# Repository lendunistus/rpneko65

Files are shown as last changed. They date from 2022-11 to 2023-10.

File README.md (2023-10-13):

# RPNeko65

**This revision has several flaws. I do not recommend actually getting this manufactured. A second revision is currently work-in-progress in the rev2 branch.**

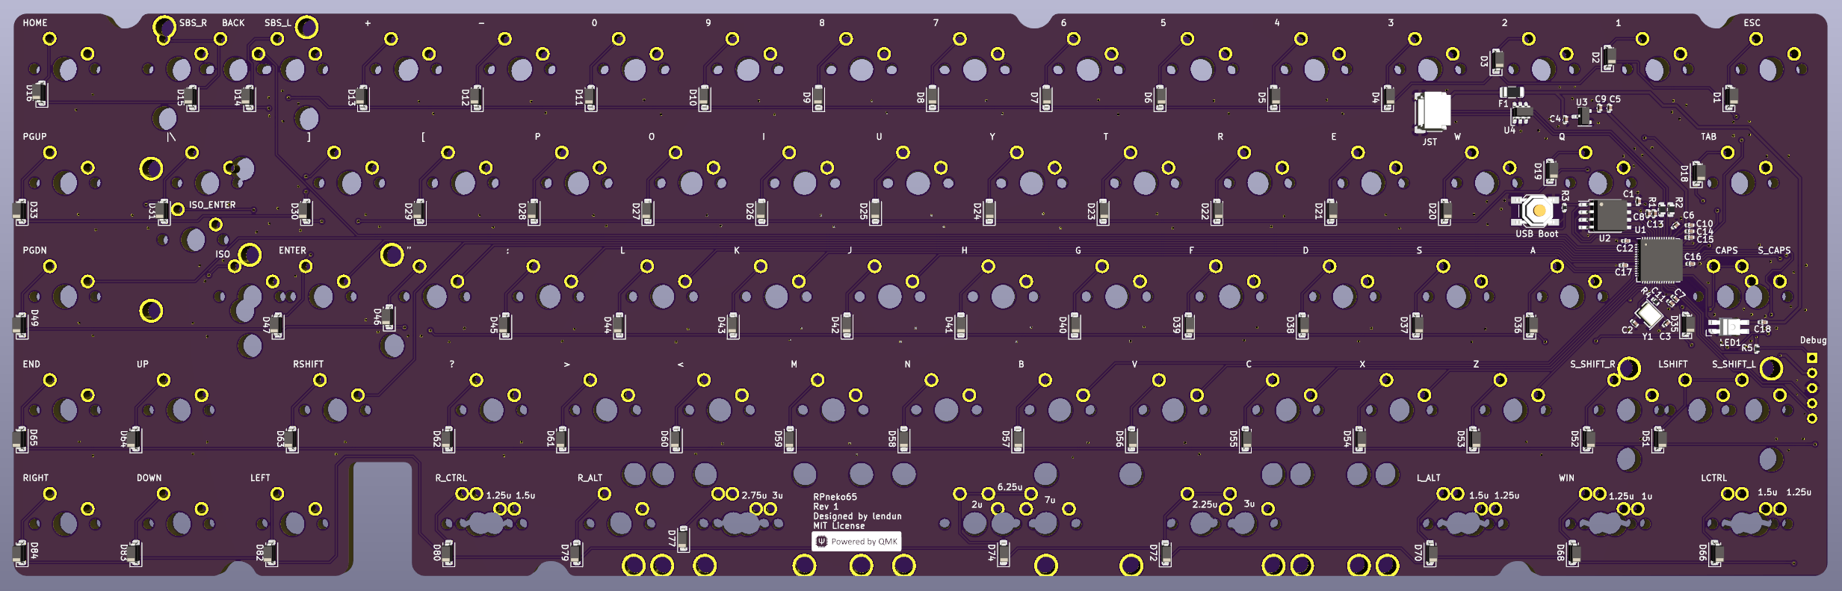
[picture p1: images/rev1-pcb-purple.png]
PCB Image


An open source multi-layout PCB for the [Bakeneko65](https://github.com/kkatano/bakeneko-65)

## Features
- QMK/VIA
- RGB LED under Caps Lock (currently non-functional without modification)
- Large amount of layout support
- C3 Unified Daughterboard
- Support for clip-in stabilizers

## Layout support
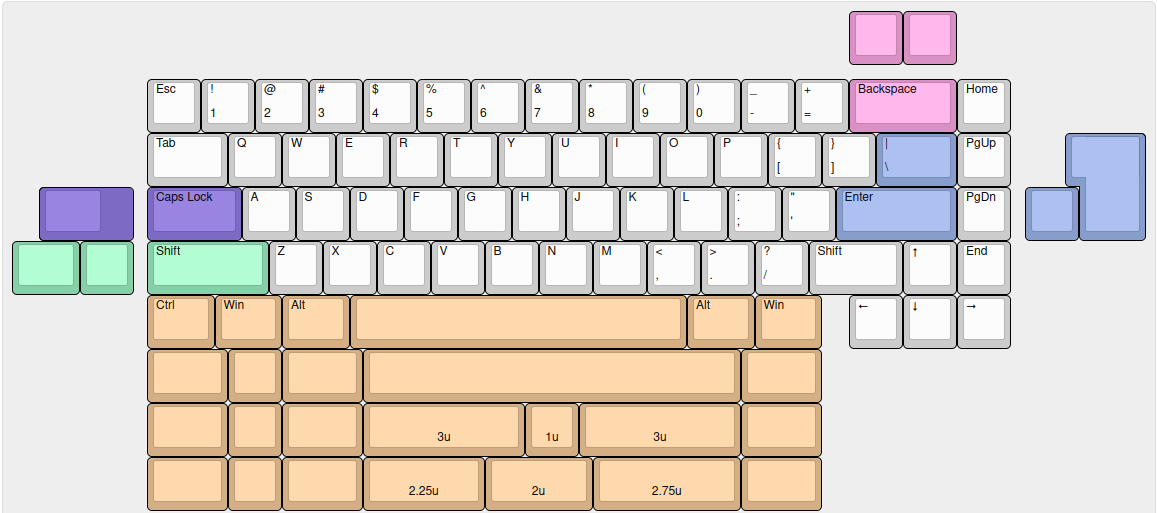
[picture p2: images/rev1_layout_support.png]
Layout Support


## Release history
- Rev 1: Initial prototype. Caps Lock LED is non-functional due to incorrect capacitor wiring, can be fixed by removing the capacitor and bridging the two pads. ANSI enter and spacebar stabiliser holes are also misaligned

## Credits
- kkatano for creating the original Bakeneko65
- Zykrah for their [firmware script](https://github.com/zykrah/firmware-scripts)
- MarvFPV and ebastler for [marbastlib](https://github.com/ebastler/marbastlib)
- Sleepdealer for their [RP2040 design guide](https://github.com/Sleepdealr/RP2040-designguide)
- People in the Keyboard Atelier server for the help and assistance

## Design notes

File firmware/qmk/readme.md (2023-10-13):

# rpneko65

rpneko65\
*PCB rear side*

A multi-layout PCB designed to fit the Bakeneko65 case by kkatano.

* Keyboard Maintainer: [lendunistus](https://github.com/lendunistus)
* Hardware Supported: RPNeko65 PCB; [Bakeneko65 V3 Case](https://github.com/kkatano/bakeneko-65)
* Hardware Availability: [Open source on GitHub](https://github.com/lendunistus/rpneko65)

Make example for this keyboard (after setting up your build environment):

    make lendunistus/rpneko65/rev1:default

Flashing example for this keyboard:

    make lendunistus/rpneko65/rev1:default:flash

See the [build environment setup](https://docs.qmk.fm/#/getting_started_build_tools) and the [make instructions](https://docs.qmk.fm/#/getting_started_make_guide) for more information. Brand new to QMK? Start with our [Complete Newbs Guide](https://docs.qmk.fm/#/newbs).

## Bootloader

Plug in the keyboard while holding down either the ESC key or the button on the back of the PCB labelled "USB Boot".

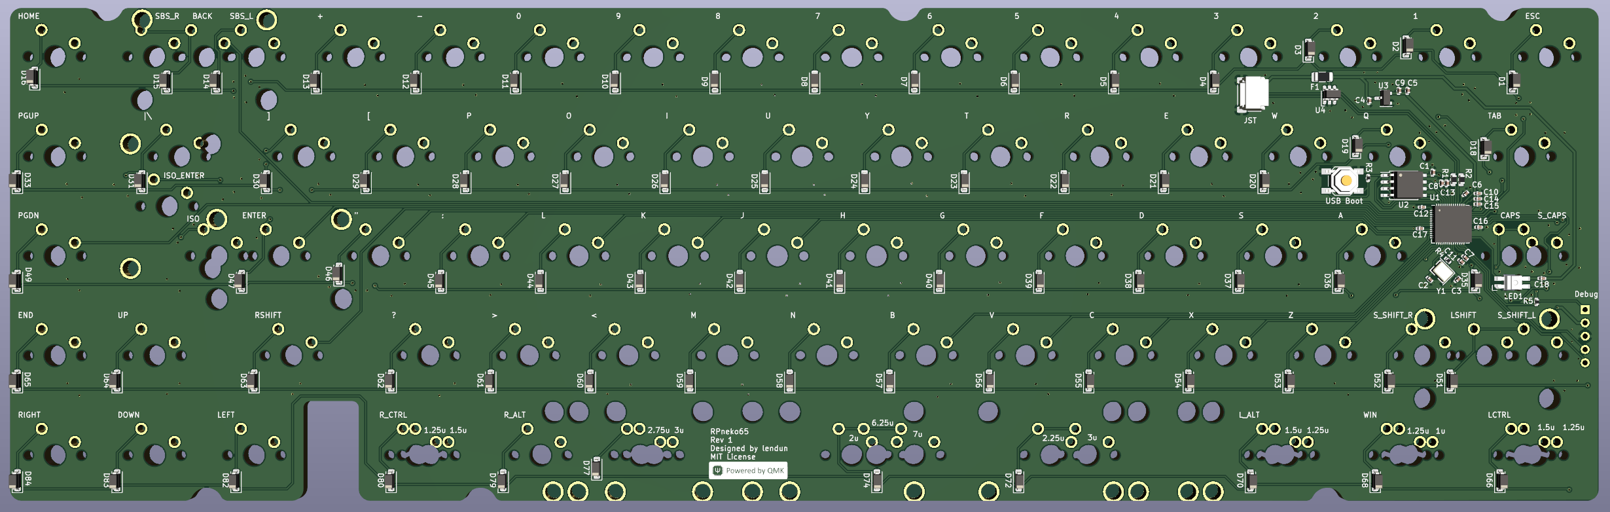
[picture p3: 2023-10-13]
images/rev1-pcb.png

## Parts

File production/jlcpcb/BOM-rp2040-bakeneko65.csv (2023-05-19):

Comment | Designator | Footprint | LCSC
1k | R3,R4,R5 | R_0402_1005Metric | C11702
500mA | F1 | Fuse_1206_3216Metric | C151162
22pF | C2,C3 | C_0402_1005Metric | C1555
SM04B-SRSS-TB | J1 | JST_SH_SM04B-SRSS-TB_1x04-1MP_P1.00mm_Horizontal | C160404
RP2040 | U1 | QFN-56-1EP_7x7mm_P0.4mm_EP3.2x3.2mm | C2040
4.7uF | C9 | C_0402_1005Metric | C23733
27 | R1,R2 | R_0603_1608Metric | C25190
100nF | C1,C11,C12,C13,C14,C15,C16,C17,C18,C7,C8 | C_0402_1005Metric | C307331
SW_Push | SW85 | SW_SPST_SKQG_WithStem | C318884
SK6812 Mini-E | LED1 | LED_MX_6028R | C524051
1uF | C10,C4,C5,C6 | C_0402_1005Metric | C52923
XC6206PxxxMR | U3 | SOT-23 | C5446
1N4148 | D1,D10,D11,D12,D13,D14,D15,D16,D18,D19,D2,D20,D21,D22,D23,D24,D25,D26,D27,D28,D29,D3,D30,D31,D33,D35,D36,D37,D38,D39,D4,D40,D41,D42,D43,D44,D45,D46,D47,D49,D5,D51,D52,D53,D54,D55,D56,D57,D58,D59,D6,D60,D61,D62,D63,D64,D65,D66,D68,D7,D70,D72,D74,D77,D79,D8,D80,D82,D83,D84,D9 | D_SOD-123 | C81598
SRV05 | U4 | SOT-23-6-routable | C85364
12MHz | Y1 | Crystal_SMD_3225-4Pin_3.2x2.5mm | C9002
W25Q128JVS | U2 | SOIC-8_5.23x5.23mm_P1.27mm | C97521

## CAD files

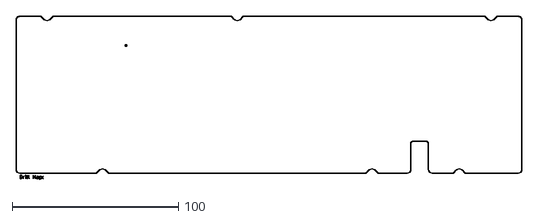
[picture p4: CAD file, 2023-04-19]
plate/kicad-plate/rp2040-bakeneko65-NPTH-drl_map.dxf
303.8 x 98.1

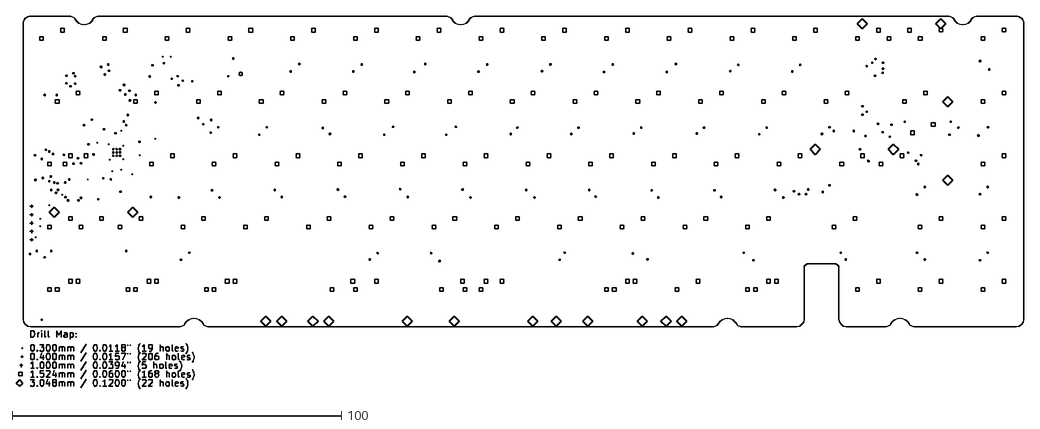
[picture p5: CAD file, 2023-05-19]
production/gerbers/rp2040-bakeneko65-PTH-drl_map.dxf
305.9 x 113.0

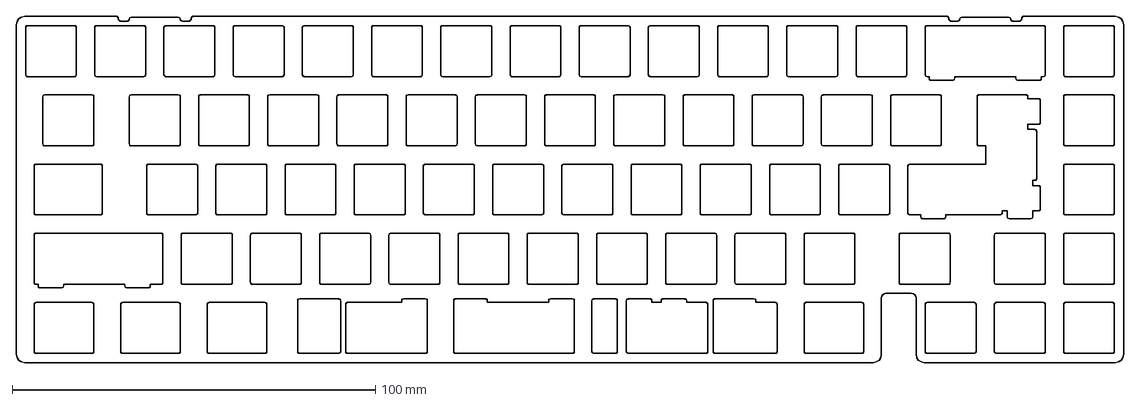
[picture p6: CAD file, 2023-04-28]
production/rpneko65-plate.dxf
304.8 x 95.3 mm

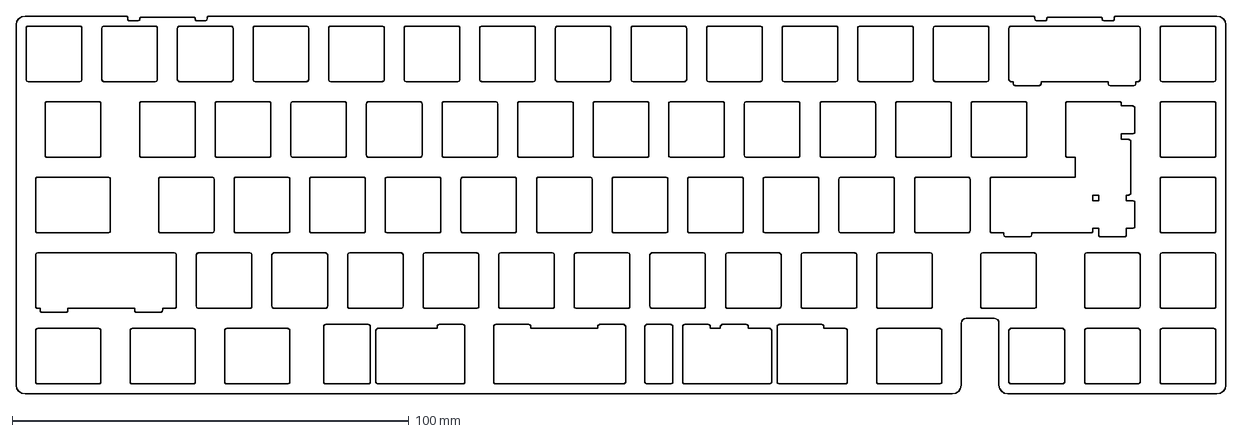
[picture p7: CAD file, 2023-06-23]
plate/rpneko65-plate-fixed.dxf
304.8 x 95.3 mm

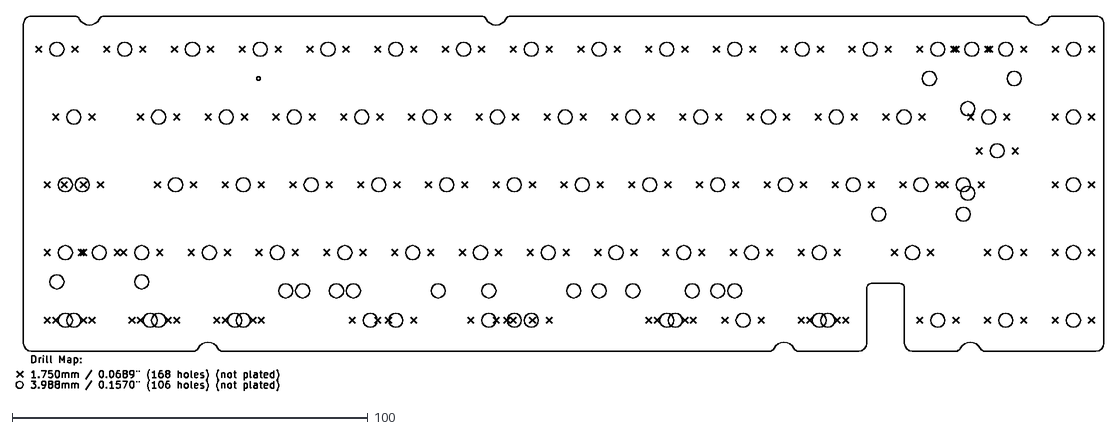
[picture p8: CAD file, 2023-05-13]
production/gerbers/rp2040-bakeneko65-NPTH-drl_map.dxf
305.9 x 105.3

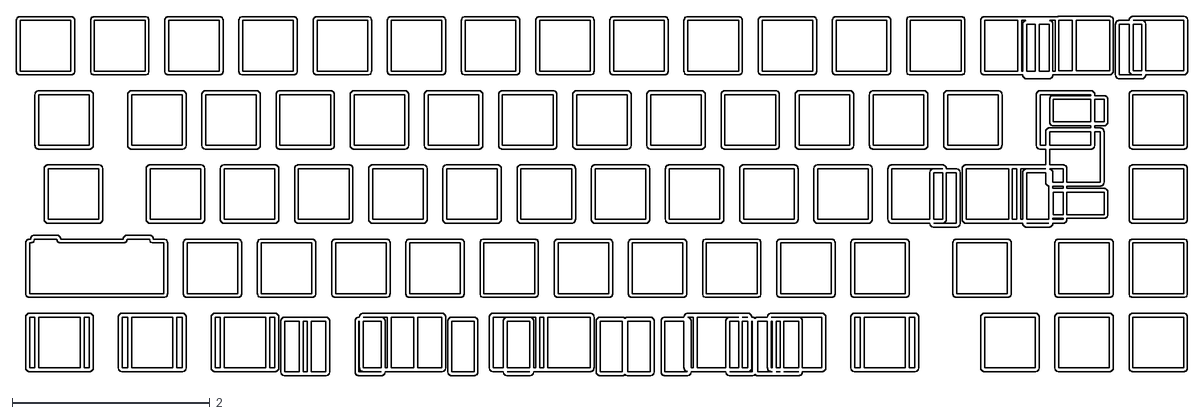
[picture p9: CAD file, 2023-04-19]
plate/kicad-plate/rp2040-bakeneko65-B_Cu.dxf
11.8 x 3.63

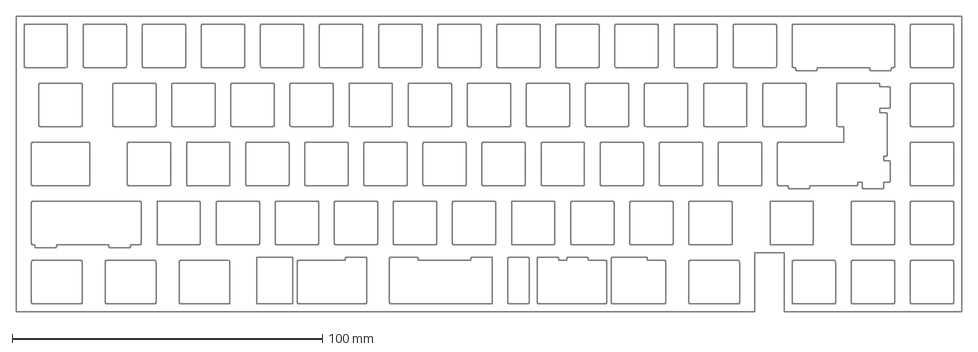
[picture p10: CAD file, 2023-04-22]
plate/keebio-plate-qcad-project.dxf
304.8 x 95.2 mm

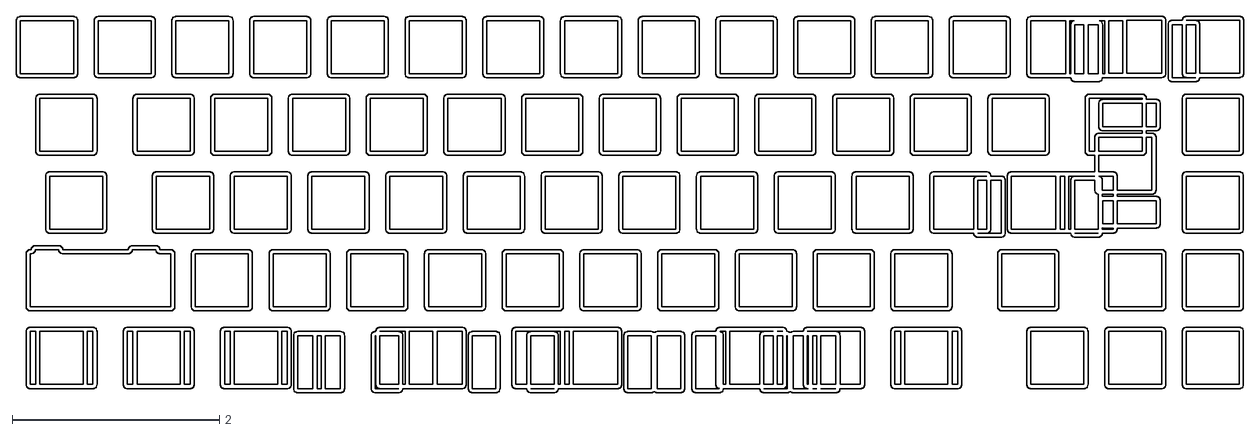
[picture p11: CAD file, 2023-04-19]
plate/kicad-plate/rp2040-bakeneko65-F_Cu.dxf
11.8 x 3.63

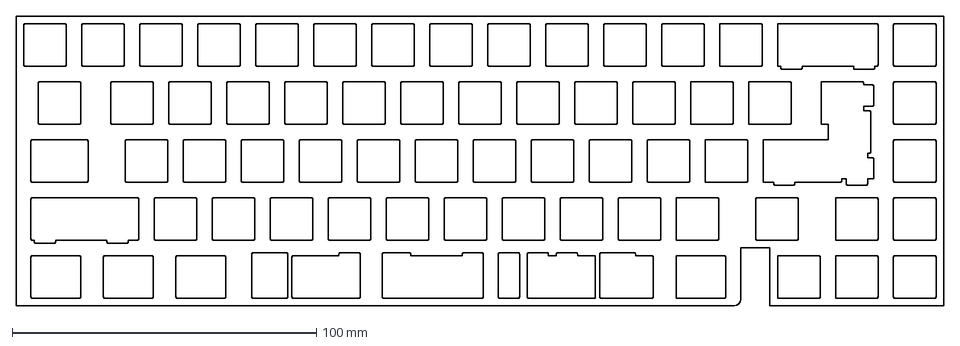
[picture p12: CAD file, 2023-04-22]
plate/keebio-plate-qcad.dxf
304.8 x 95.2 mm

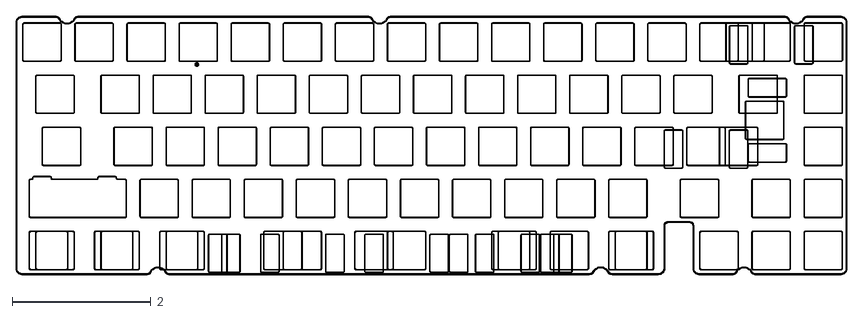
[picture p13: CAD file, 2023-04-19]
plate/kicad-plate/rp2040-bakeneko65-Edge_Cuts.dxf
12.0 x 3.72

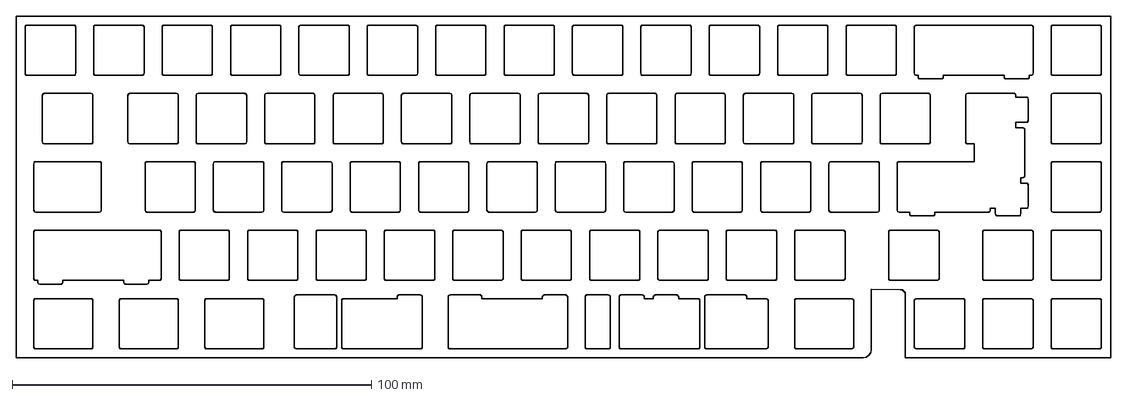
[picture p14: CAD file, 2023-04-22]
plate/keebio-plate-experiment-2.dxf
304.8 x 95.2 mm

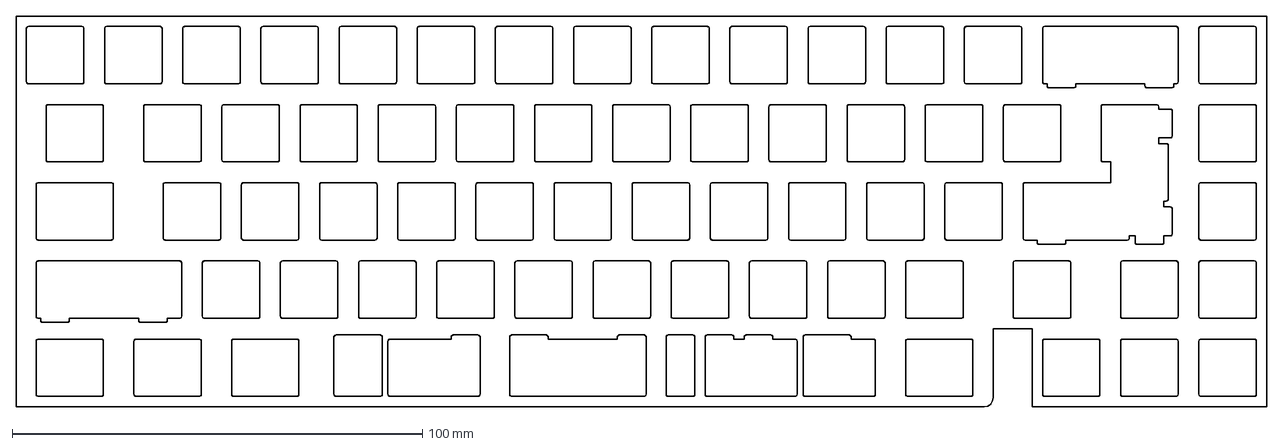
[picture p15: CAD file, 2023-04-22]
plate/keebio-plate-experiment.dxf
304.8 x 95.2 mm

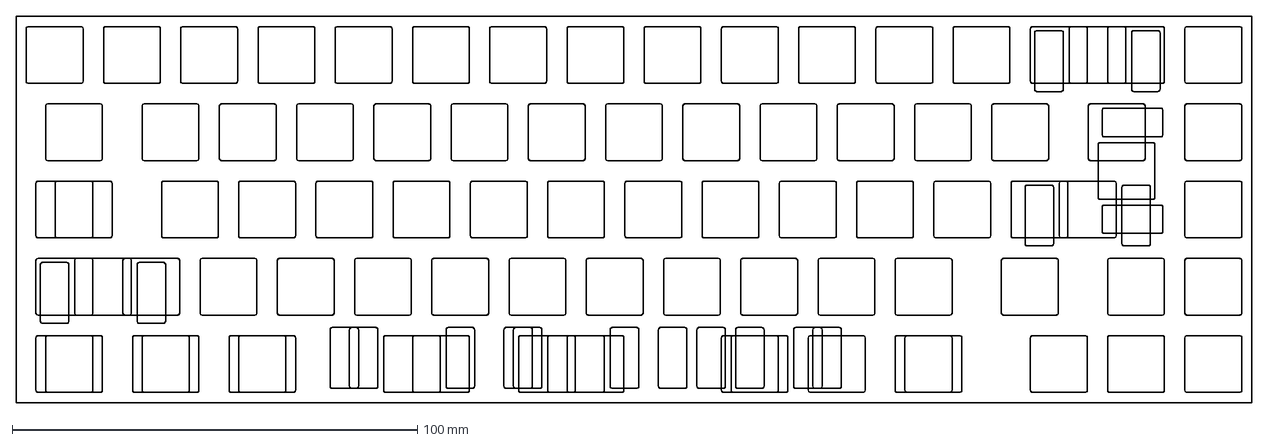
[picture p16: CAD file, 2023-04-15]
plate/plate.dxf
304.8 x 95.2 mm

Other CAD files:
plate/keebio-plate-fixed.FCStd
plate/keebio-plate.FCStd
plate/plate-inprogress.FCStd
plate/keebio-plate.dxf

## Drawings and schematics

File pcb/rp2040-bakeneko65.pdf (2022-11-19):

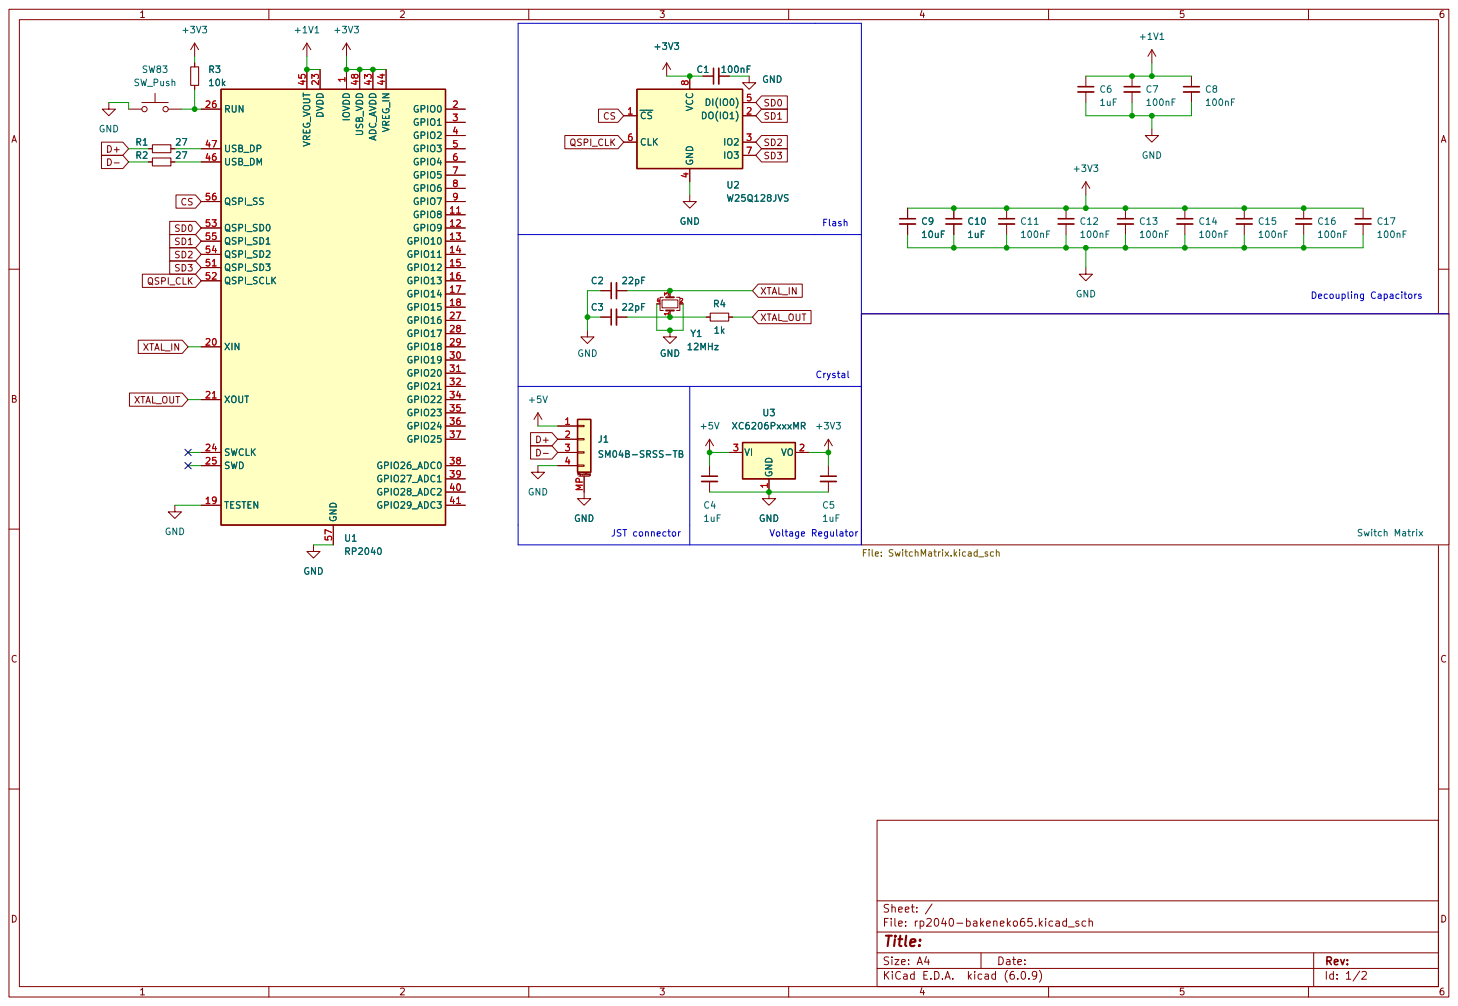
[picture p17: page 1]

1 GPIO8 11 GPIO9 12 GPIO10 13 GPIO11 14 GPIO12 15 GPIO13 16 GPIO14 17 GPIO15 18 TESTEN 19 GPIO0 2 XIN 20 XOUT 21 DVDD 23 SWCLK 24 SWD 25 RUN 26 GPIO16 27 GPIO17 28 GPIO18 29 GPIO1 3 GPIO19 30 GPIO20 31 GPIO21 32 GPIO22 34 GPIO23 35 GPIO24 36 GPIO25 37 GPIO26_ADC0 38 GPIO27_ADC1 39 GPIO2 4 GPIO28_ADC2 40 GPIO29_ADC3 41 ADC_AVDD 43 VREG_IN 44 VREG_VOUT 45 USB_DM 46 USB_DP 47 USB_VDD 48 GPIO3 5 QSPI_SD3 51 QSPI_SCLK 52 QSPI_SD0 53 QSPI_SD2 54 QSPI_SD1 55 QSPI_SS 56 GND 57 GPIO4 6 GPIO5 7 GPIO6 8 GPIO7 9 U1RP2040

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

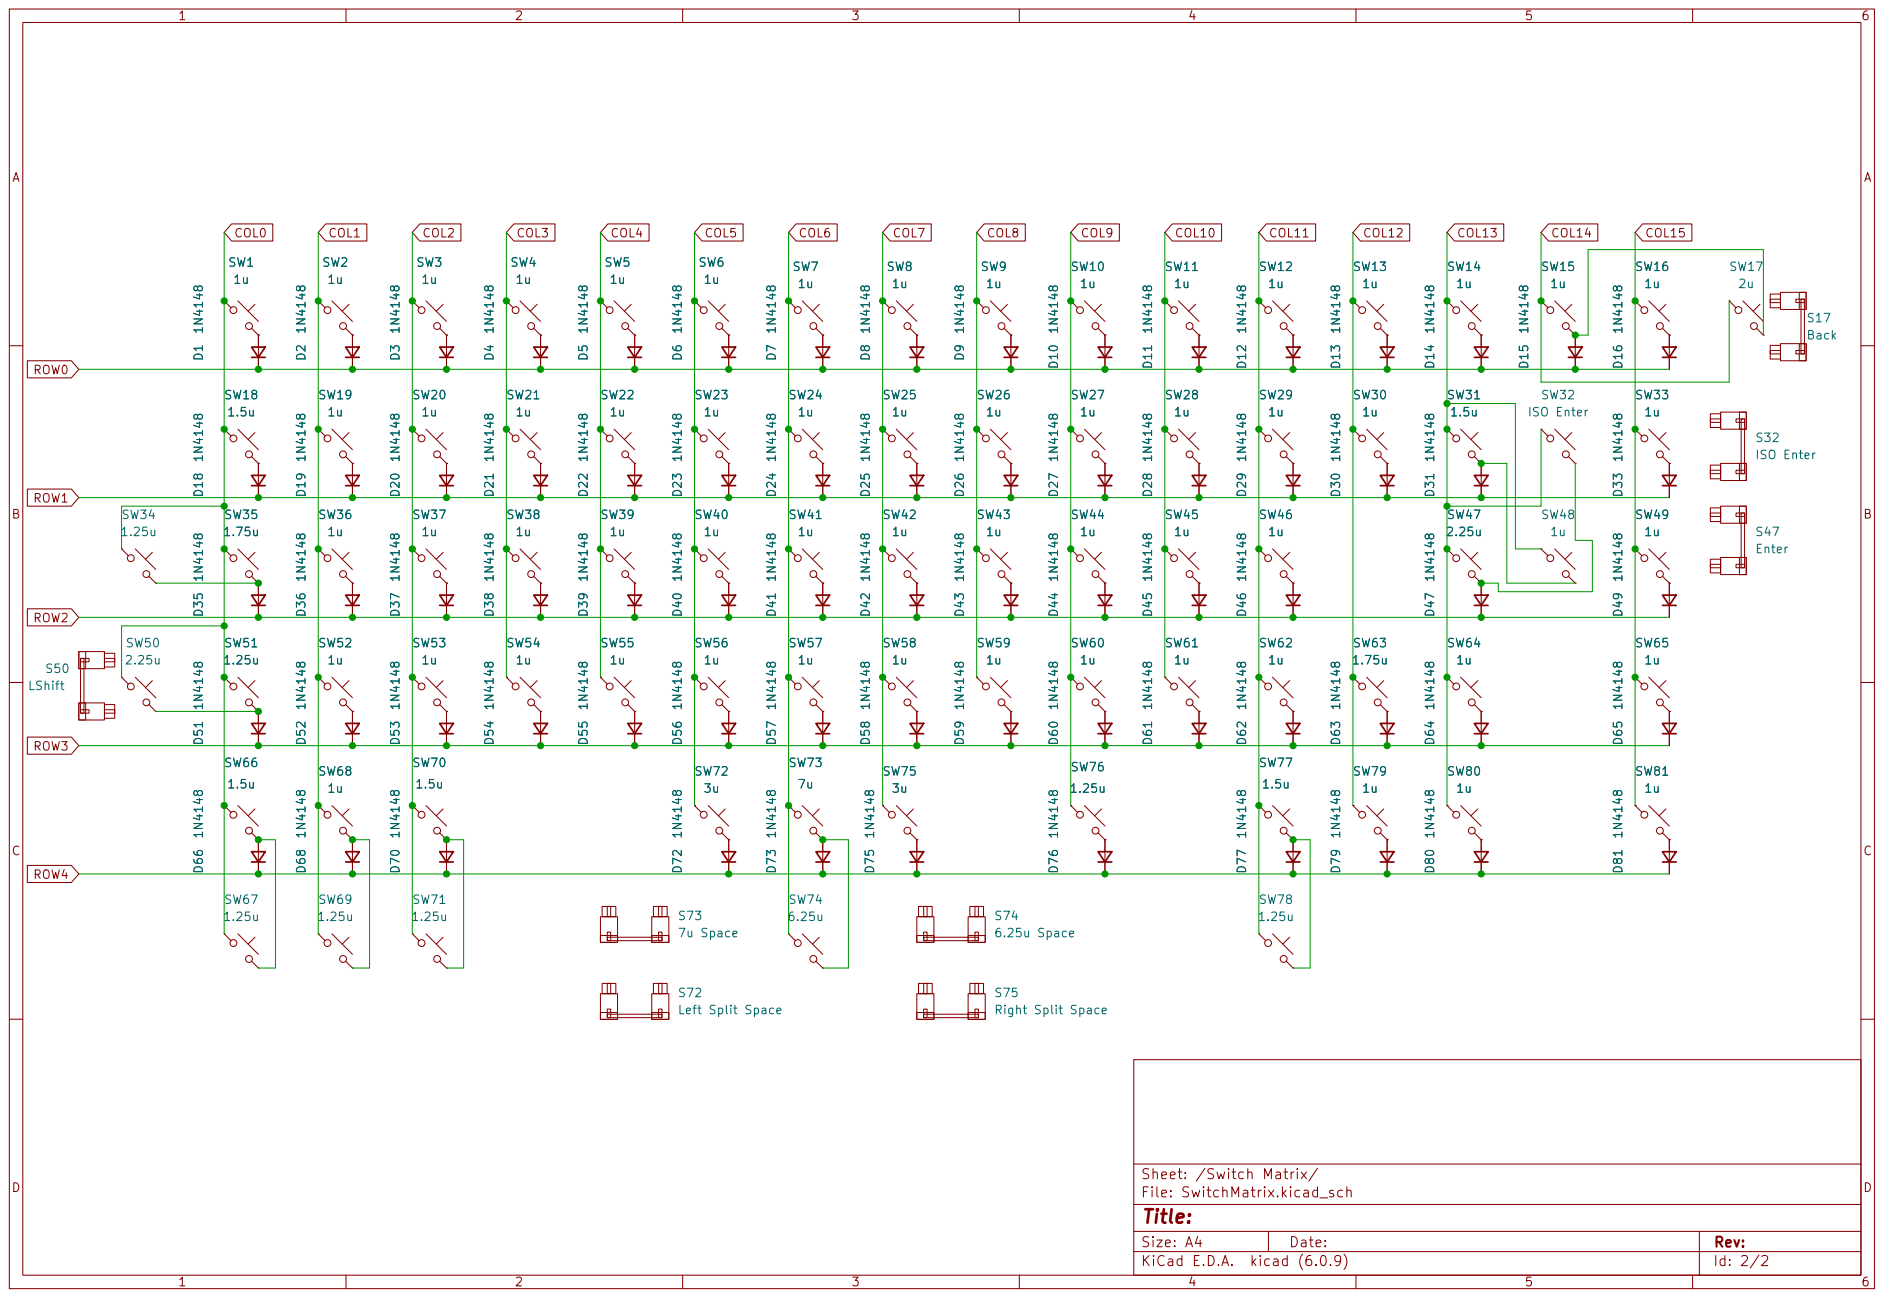
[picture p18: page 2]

File: SwitchMatrix.kicad_sch Sheet: /Switch Matrix/
Id: 2/2 Title:

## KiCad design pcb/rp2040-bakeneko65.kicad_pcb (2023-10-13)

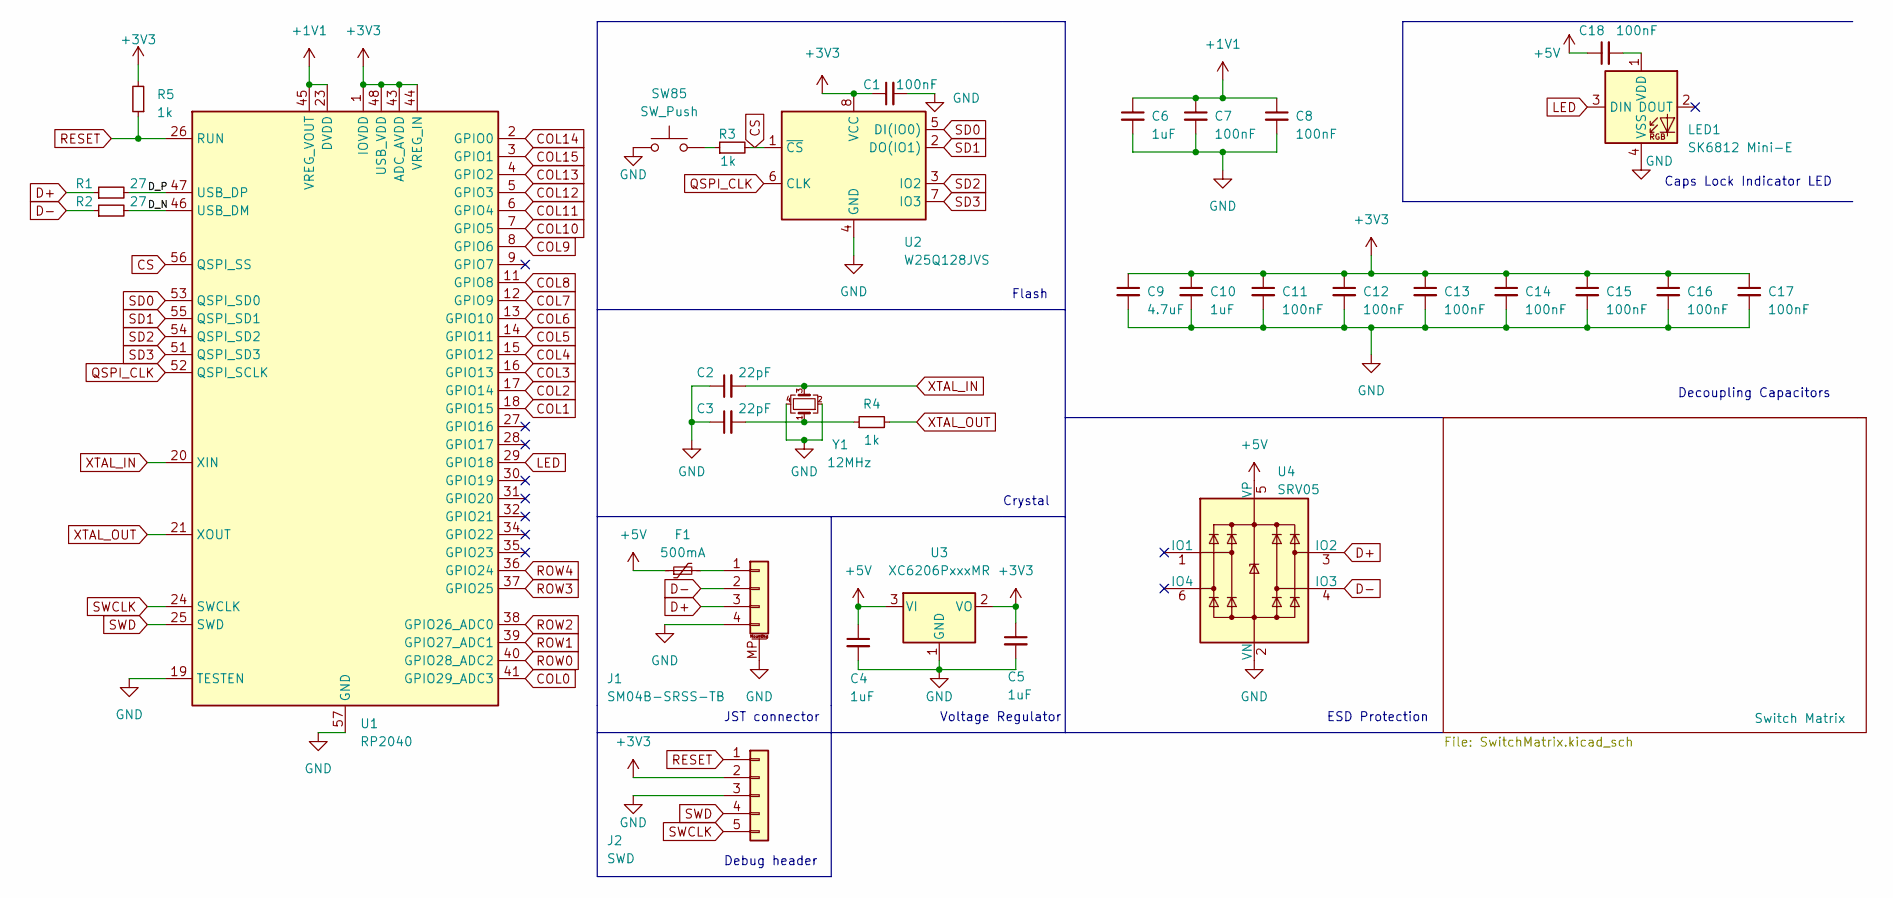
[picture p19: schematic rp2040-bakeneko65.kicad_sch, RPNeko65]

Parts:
C1, C7, C8, C11, C12, C13, C14, C15, C16, C17, C18: 100nF; C_0402_1005Metric
C2, C3: 22pF; C_0402_1005Metric
C4, C5, C6, C10: 1uF; C_0402_1005Metric
C9: 4.7uF; C_0402_1005Metric
F1: 500mA; Fuse_1206_3216Metric
J1: SM04B-SRSS-TB; JST_SH_SM04B-SRSS-TB_1x04-1MP_P1.00mm_Horizontal
J2: SWD; PinSocket_1x05_P2.54mm_Vertical
LED1: SK6812 Mini-E; LED_MX_6028R
R1, R2: 27; R_0603_1608Metric
R3, R4, R5: 1k; R_0402_1005Metric
SW85: SW_Push; SW_SPST_SKQG_WithStem
U1: RP2040; QFN-56-1EP_7x7mm_P0.4mm_EP3.2x3.2mm
U2: W25Q128JVS; SOIC-8_5.23x5.23mm_P1.27mm
U3: XC6206PxxxMR; SOT-23
U4: SRV05; SOT-23-6-routable
Y1: 12MHz; Crystal_SMD_3225-4Pin_3.2x2.5mm

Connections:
+1V1: C6.1, C7.1, C8.1, U1.23 (DVDD), U1.45 (VREG_VOUT), U1.50 (DVDD)
+3V3: C1.1, C5.1, C9.1, C10.1, C11.1, C12.1, C13.1, C14.1, C15.1, C16.1, C17.1, J2.2, R5.2, U1.1 (IOVDD), U1.10 (IOVDD), U1.22 (IOVDD), U1.33 (IOVDD), U1.42 (IOVDD), U1.43 (ADC_AVDD), U1.44 (VREG_IN), U1.48 (USB_VDD), U1.49 (IOVDD), U2.8 (VCC), U3.2 (VO)
+5V: C4.1, C18.1, F1.1, U3.3 (VI), U4.5 (VP)
/D_N: R2.2, U1.46 (USB_DM)
/D_P: R1.2, U1.47 (USB_DP)
COL0: U1.41 (GPIO29_ADC3); also elsewhere on the board
COL1: U1.18 (GPIO15); also elsewhere on the board
COL2: U1.17 (GPIO14); also elsewhere on the board
COL3: U1.16 (GPIO13); also elsewhere on the board
COL4: U1.15 (GPIO12); also elsewhere on the board
COL5: U1.14 (GPIO11); also elsewhere on the board
COL6: U1.13 (GPIO10); also elsewhere on the board
COL7: U1.12 (GPIO9); also elsewhere on the board
COL8: U1.11 (GPIO8); also elsewhere on the board
COL9: U1.8 (GPIO6); also elsewhere on the board
COL10: U1.7 (GPIO5); also elsewhere on the board
COL11: U1.6 (GPIO4); also elsewhere on the board
COL12: U1.5 (GPIO3); also elsewhere on the board
COL13: U1.4 (GPIO2); also elsewhere on the board
COL14: U1.2 (GPIO0); also elsewhere on the board
COL15: U1.3 (GPIO1); also elsewhere on the board
CS: R3.2, U1.56 (QSPI_SS), U2.1 (~CS)
D+: J1.3, R1.1, U4.3 (IO2)
D-: J1.2, R2.1, U4.4 (IO3)
GND: C1.2, C2.1, C3.1, C4.2, C5.2, C6.2, C7.2, C8.2, C9.2, C10.2, C11.2, C12.2, C13.2, C14.2, C15.2, C16.2, C17.2, J1.4, J1.MP (MountPin), J2.3, LED1.4 (VSS), SW85.1, U1.19 (TESTEN), U1.57 (GND), U2.4 (GND), U3.1 (GND), U4.2 (VN), Y1.2, Y1.4
LED: LED1.3 (DIN), U1.29 (GPIO18)
unnamed: C3.2, R4.1, Y1.1
unnamed: F1.2, J1.1
unnamed: C18.2, LED1.1 (VDD)
unnamed: R3.1, SW85.2
QSPI_CLK: U1.52 (QSPI_SCLK), U2.6 (CLK)
RESET: J2.1, R5.1, U1.26 (RUN)
ROW0: U1.40 (GPIO28_ADC2); also elsewhere on the board
ROW1: U1.39 (GPIO27_ADC1); also elsewhere on the board
ROW2: U1.38 (GPIO26_ADC0); also elsewhere on the board
ROW3: U1.37 (GPIO25); also elsewhere on the board
ROW4: U1.36 (GPIO24); also elsewhere on the board
SD0: U1.53 (QSPI_SD0), U2.5 (DI(IO0))
SD1: U1.55 (QSPI_SD1), U2.2 (DO(IO1))
SD2: U1.54 (QSPI_SD2), U2.3 (IO2)
SD3: U1.51 (QSPI_SD3), U2.7 (IO3)
SWCLK: J2.5, U1.24 (SWCLK)
SWD: J2.4, U1.25 (SWD)
XTAL_IN: C2.2, U1.20 (XIN), Y1.3
XTAL_OUT: R4.2, U1.21 (XOUT)

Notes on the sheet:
Voltage Regulator
Flash
JST connector
ESD Protection
Crystal
Caps Lock Indicator LED
Decoupling Capacitors
Debug header

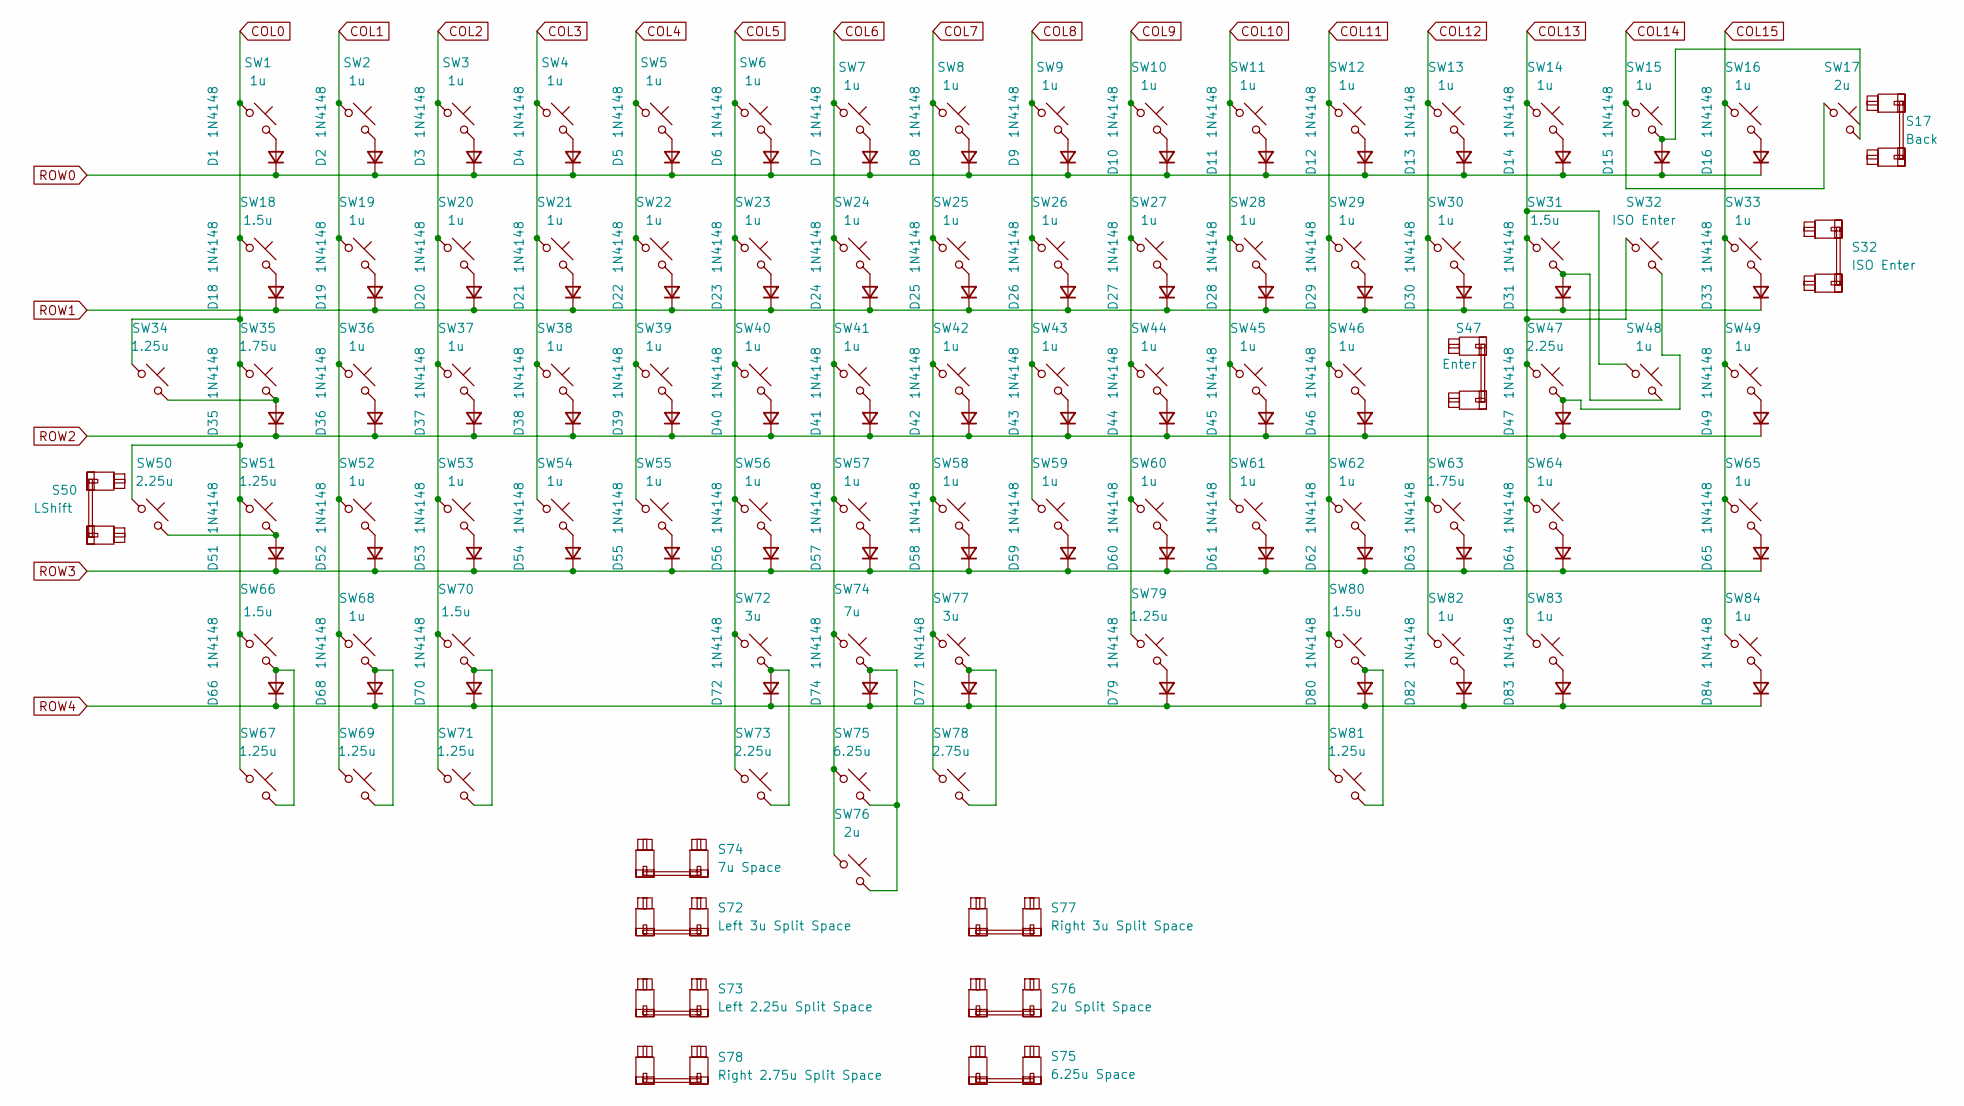
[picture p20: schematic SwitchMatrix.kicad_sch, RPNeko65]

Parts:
D1, D2, D3, D4, D5, D6, D7, D8, D9, D10, D11, D12, D13, D14, D15, D16, D18, D19, D20, D21, D22, D23, D24, D25, D26, D27, D28, D29, D30, D31, D33, D35, D36, D37, D38, D39, D40, D41, D42, D43, D44, D45, D46, D47, D49, D51, D52, D53, D54, D55, D56, D57, D58, D59, D60, D61, D62, D63, D64, D65, D66, D68, D70, D72, D74, D77, D79, D80, D82, D83, D84: 1N4148; D_SOD-123
S17: Back; STAB_MX_P_2u
S32: ISO Enter; STAB_MX_P_ISO
S47: Enter; STAB_MX_P_2.25u
S50: LShift; STAB_MX_P_2.25u
S72: Left 3u Split Space; STAB_MX_P_3u
S73: Left 2.25u Split Space; STAB_MX_P_2.25u
S74: 7u Space; STAB_MX_P_7u
S75: 6.25u Space; STAB_MX_P_6.25u
S76: 2u Split Space; STAB_MX_P_2u
S77: Right 3u Split Space; STAB_MX_P_3u
S78: Right 2.75u Split Space; STAB_MX_P_2.75u
SW1, SW2, SW3, SW4, SW5, SW6, SW7, SW8, SW9, SW10, SW11, SW12, SW13, SW14, SW15, SW16, SW19, SW20, SW21, SW22, SW23, SW24, SW25, SW26, SW27, SW28, SW29, SW30, SW33, SW36, SW37, SW38, SW39, SW40, SW41, SW42, SW43, SW44, SW45, SW46, SW48, SW49, SW52, SW53, SW54, SW55, SW56, SW57, SW58, SW59, SW60, SW61, SW62, SW64, SW65, SW68, SW82, SW83, SW84: 1u; SW_MX_1u
SW17, SW76: 2u; SW_MX_1u
SW18, SW31, SW66, SW70, SW80: 1.5u; SW_MX_1.5u
SW32: ISO Enter; SW_MX_1u
SW34, SW51, SW67, SW69, SW71, SW79, SW81: 1.25u; SW_MX_1.25u
SW35, SW63: 1.75u; SW_MX_1.75u
SW47, SW50, SW73: 2.25u; SW_MX_1u
SW72, SW77: 3u; SW_MX_1u
SW74: 7u; SW_MX_1u
SW75: 6.25u; SW_MX_1u
SW78: 2.75u; SW_MX_1u

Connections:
COL0: SW1.1, SW18.1, SW34.1, SW35.1, SW50.1, SW51.1, SW66.1, SW67.1; also elsewhere on the board
COL1: SW2.1, SW19.1, SW36.1, SW52.1, SW68.1, SW69.1; also elsewhere on the board
COL2: SW3.1, SW20.1, SW37.1, SW53.1, SW70.1, SW71.1; also elsewhere on the board
COL3: SW4.1, SW21.1, SW38.1, SW54.1; also elsewhere on the board
COL4: SW5.1, SW22.1, SW39.1, SW55.1; also elsewhere on the board
COL5: SW6.1, SW23.1, SW40.1, SW56.1, SW72.1, SW73.1; also elsewhere on the board
COL6: SW7.1, SW24.1, SW41.1, SW57.1, SW74.1, SW75.1, SW76.1; also elsewhere on the board
COL7: SW8.1, SW25.1, SW42.1, SW58.1, SW77.1, SW78.1; also elsewhere on the board
COL8: SW9.1, SW26.1, SW43.1, SW59.1; also elsewhere on the board
COL9: SW10.1, SW27.1, SW44.1, SW60.1, SW79.1; also elsewhere on the board
COL10: SW11.1, SW28.1, SW45.1, SW61.1; also elsewhere on the board
COL11: SW12.1, SW29.1, SW46.1, SW62.1, SW80.1, SW81.1; also elsewhere on the board
COL12: SW13.1, SW30.1, SW63.1, SW82.1; also elsewhere on the board
COL13: SW14.1, SW31.1, SW32.1, SW47.1, SW48.1, SW64.1, SW83.1; also elsewhere on the board
COL14: SW15.1, SW17.1; also elsewhere on the board
COL15: SW16.1, SW33.1, SW49.1, SW65.1, SW84.1; also elsewhere on the board
unnamed: D1.2 (A), SW1.2
unnamed: D2.2 (A), SW2.2
unnamed: D3.2 (A), SW3.2
unnamed: D4.2 (A), SW4.2
unnamed: D5.2 (A), SW5.2
unnamed: D6.2 (A), SW6.2
unnamed: D7.2 (A), SW7.2
unnamed: D8.2 (A), SW8.2
unnamed: D9.2 (A), SW9.2
unnamed: D10.2 (A), SW10.2
unnamed: D11.2 (A), SW11.2
unnamed: D12.2 (A), SW12.2
unnamed: D13.2 (A), SW13.2
unnamed: D14.2 (A), SW14.2
unnamed: D15.2 (A), SW15.2, SW17.2
unnamed: D16.2 (A), SW16.2
unnamed: D18.2 (A), SW18.2
unnamed: D19.2 (A), SW19.2
unnamed: D20.2 (A), SW20.2
unnamed: D21.2 (A), SW21.2
unnamed: D22.2 (A), SW22.2
unnamed: D23.2 (A), SW23.2
unnamed: D24.2 (A), SW24.2
unnamed: D25.2 (A), SW25.2
unnamed: D26.2 (A), SW26.2
unnamed: D27.2 (A), SW27.2
unnamed: D28.2 (A), SW28.2
unnamed: D29.2 (A), SW29.2
unnamed: D30.2 (A), SW30.2
unnamed: D31.2 (A), SW31.2, SW48.2
unnamed: D33.2 (A), SW33.2
unnamed: D35.2 (A), SW34.2, SW35.2
unnamed: D36.2 (A), SW36.2
unnamed: D37.2 (A), SW37.2
unnamed: D38.2 (A), SW38.2
unnamed: D39.2 (A), SW39.2
unnamed: D40.2 (A), SW40.2
unnamed: D41.2 (A), SW41.2
unnamed: D42.2 (A), SW42.2
unnamed: D43.2 (A), SW43.2
unnamed: D44.2 (A), SW44.2
unnamed: D45.2 (A), SW45.2
unnamed: D46.2 (A), SW46.2
unnamed: D47.2 (A), SW32.2, SW47.2
unnamed: D49.2 (A), SW49.2
unnamed: D51.2 (A), SW50.2, SW51.2
unnamed: D52.2 (A), SW52.2
unnamed: D53.2 (A), SW53.2
unnamed: D54.2 (A), SW54.2
unnamed: D55.2 (A), SW55.2
unnamed: D56.2 (A), SW56.2
unnamed: D57.2 (A), SW57.2
unnamed: D58.2 (A), SW58.2
unnamed: D59.2 (A), SW59.2
unnamed: D60.2 (A), SW60.2
unnamed: D61.2 (A), SW61.2
unnamed: D62.2 (A), SW62.2
unnamed: D63.2 (A), SW63.2
unnamed: D64.2 (A), SW64.2
unnamed: D65.2 (A), SW65.2
unnamed: D66.2 (A), SW66.2, SW67.2
unnamed: D68.2 (A), SW68.2, SW69.2
unnamed: D70.2 (A), SW70.2, SW71.2
unnamed: D72.2 (A), SW72.2, SW73.2
unnamed: D74.2 (A), SW74.2, SW75.2, SW76.2
unnamed: D77.2 (A), SW77.2, SW78.2
unnamed: D79.2 (A), SW79.2
unnamed: D80.2 (A), SW80.2, SW81.2
unnamed: D82.2 (A), SW82.2
unnamed: D83.2 (A), SW83.2
unnamed: D84.2 (A), SW84.2
ROW0: D1.1 (K), D2.1 (K), D3.1 (K), D4.1 (K), D5.1 (K), D6.1 (K), D7.1 (K), D8.1 (K), D9.1 (K), D10.1 (K), D11.1 (K), D12.1 (K), D13.1 (K), D14.1 (K), D15.1 (K), D16.1 (K); also elsewhere on the board
ROW1: D18.1 (K), D19.1 (K), D20.1 (K), D21.1 (K), D22.1 (K), D23.1 (K), D24.1 (K), D25.1 (K), D26.1 (K), D27.1 (K), D28.1 (K), D29.1 (K), D30.1 (K), D31.1 (K), D33.1 (K); also elsewhere on the board
ROW2: D35.1 (K), D36.1 (K), D37.1 (K), D38.1 (K), D39.1 (K), D40.1 (K), D41.1 (K), D42.1 (K), D43.1 (K), D44.1 (K), D45.1 (K), D46.1 (K), D47.1 (K), D49.1 (K); also elsewhere on the board
ROW3: D51.1 (K), D52.1 (K), D53.1 (K), D54.1 (K), D55.1 (K), D56.1 (K), D57.1 (K), D58.1 (K), D59.1 (K), D60.1 (K), D61.1 (K), D62.1 (K), D63.1 (K), D64.1 (K), D65.1 (K); also elsewhere on the board
ROW4: D66.1 (K), D68.1 (K), D70.1 (K), D72.1 (K), D74.1 (K), D77.1 (K), D79.1 (K), D80.1 (K), D82.1 (K), D83.1 (K), D84.1 (K); also elsewhere on the board

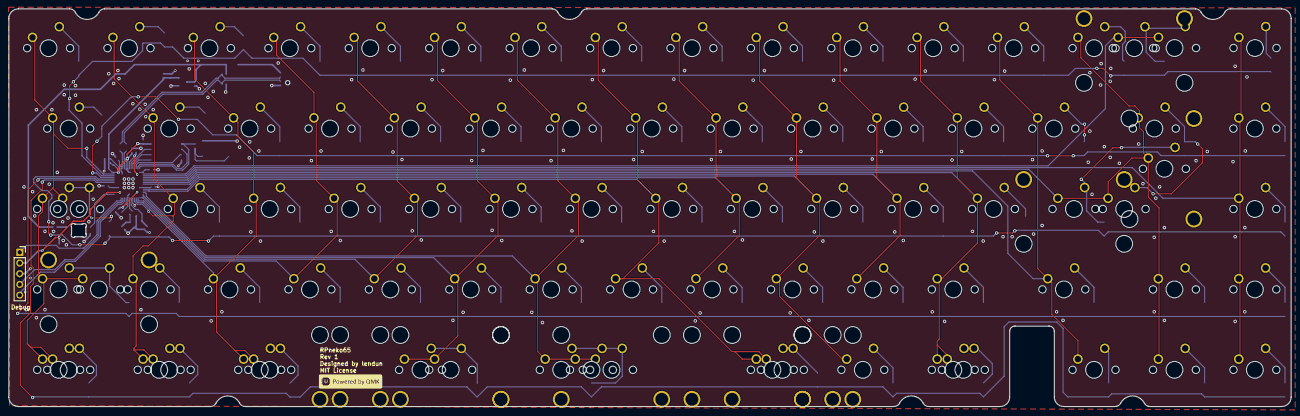
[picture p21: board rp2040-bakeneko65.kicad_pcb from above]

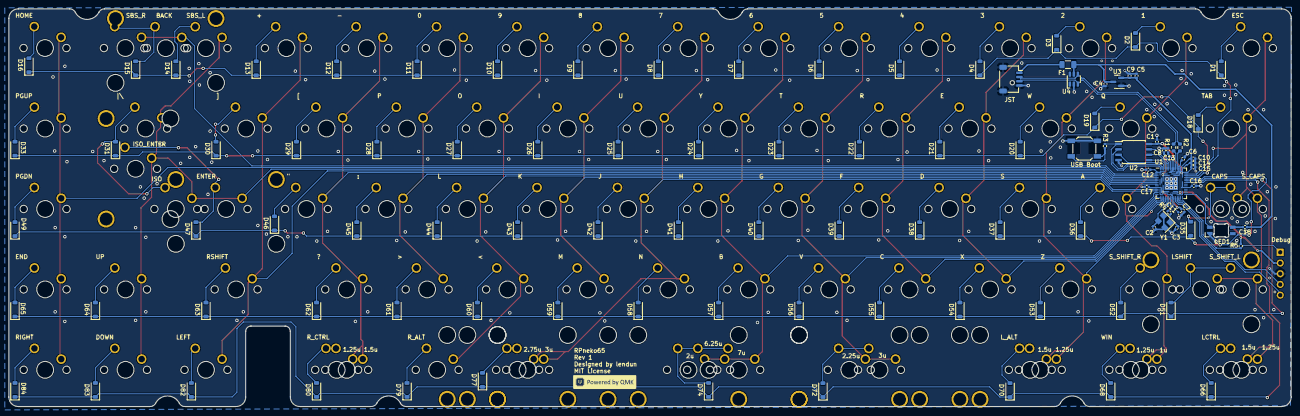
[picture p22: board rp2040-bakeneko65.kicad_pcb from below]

Board: 2 copper layers, 303.8 x 94.2 mm, 199 parts (103 on the bottom side), 116 nets.

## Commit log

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2022-11-12 JST and voltage regulator
    [rp2040-bakeneko65.kicad_sch]
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2022-11-13 Some more matrix stuff
    [SwitchMatrix.kicad_sch, rp2040-bakeneko65.kicad_sch]
2022-11-15 ISO + some wiring
    [SwitchMatrix.kicad_sch, rp2040-bakeneko65.kicad_sch]
2022-11-15 Label switches and diodes
    [SwitchMatrix.kicad_sch, rp2040-bakeneko65.kicad_sch]
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2022-11-15 Fixed split space routing
    [SwitchMatrix.kicad_sch, rp2040-bakeneko65.kicad_sch]
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2022-11-17 Move switches a bit
    [rp2040-bakeneko65.kicad_pcb]
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2022-11-17 Correct stabs
    [SwitchMatrix.kicad_sch, rp2040-bakeneko65.kicad_pcb, rp2040-bakeneko65.kicad_sch]
2022-11-17 oops, forgot ANSI enter
    [SwitchMatrix.kicad_sch, rp2040-bakeneko65.kicad_pcb, rp2040-bakeneko65.kicad_sch]
2022-11-17 Position a couple stabs
    [rp2040-bakeneko65.kicad_pcb]
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2022-11-19 Attempt to use autoplacer plugin
    [SwitchMatrix.kicad_sch, rp2040-bakeneko65 copy.kicad_pcb, rp2040-bakeneko65.kicad_sch]
2022-11-19 even more desperate attempts at autopicker
    [SwitchMatrix.kicad_sch, rp2040-bakeneko65.kicad_pcb, rp2040-bakeneko65.kicad_sch]
2022-11-19 Finally got the keys and diodes placed
    [SwitchMatrix.kicad_sch, rp2040-bakeneko65.kicad_pcb, rp2040-bakeneko65.kicad_sch]
2022-11-19 oops, messed up a couple stabs
    [rp2040-bakeneko65.kicad_pcb]
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2022-11-19 Failed attempt to route MCU traces
    [rp2040-bakeneko65.kicad_pcb]
2022-11-19 figured out MCU traces
    [rp2040-bakeneko65.kicad_pcb]
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2022-11-26 some more dumpster fire routing
    [rp2040-bakeneko65.kicad_pcb]
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2022-12-02 starting over on MCU routing
    [rp2040-bakeneko65.kicad_pcb]
2022-12-03 Use smaller caps and resistors
    [rp2040-bakeneko65.kicad_pcb, rp2040-bakeneko65.kicad_sch]
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2022-12-07 failed attempt to route USB DP/DN
    [rp2040-bakeneko65.kicad_pcb, rp2040-bakeneko65.kicad_sch]
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2022-12-08 Power and some decoupling caps
    [rp2040-bakeneko65.kicad_pcb]
2022-12-10 some stuff to prepare for fill zones
    [rp2040-bakeneko65.kicad_pcb]
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2022-12-15 Starting over on routing
    [rp2040-bakeneko65 copy.kicad_pcb, rp2040-bakeneko65.kicad_pcb]
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2022-12-16 Polyfuse and 2u split space
    [SwitchMatrix.kicad_sch, rp2040-bakeneko65.kicad_sch]
2022-12-18 Add caps lock LED symbol
    [rp2040-bakeneko65.kicad_sch]
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2022-12-18 The first switch (again)
    [rp2040-bakeneko65.kicad_pcb]
2022-12-19 Place switches (with broken stabs)
    [SwitchMatrix.kicad_sch, rp2040-bakeneko65.kicad_sch]
2022-12-19 forgot to save PCB
    [rp2040-bakeneko65.kicad_pcb]
2022-12-19 Attempt to get stabs to work
    [SwitchMatrix.kicad_sch, rp2040-bakeneko65.kicad_pcb]
2022-12-26 second (unsuccessful) attempt to fix stabs
    [SwitchMatrix.kicad_sch, rp2040-bakeneko65.kicad_pcb, rp2040-bakeneko65.kicad_sch]
2022-12-26 third unsuccessful stab fix
    [SwitchMatrix.kicad_sch, rp2040-bakeneko65.kicad_pcb, rp2040-bakeneko65.kicad_sch]
2023-01-24 Use ghost keys to fix stabs (thanks zykrah)
    [rp2040-bakeneko65.kicad_pcb]
2023-01-26 Add debug header to schematic
    [rp2040-bakeneko65.kicad_sch]
2023-03-24 Assign footprints, add knob symbol
    [SwitchMatrix.kicad_sch, rp2040-bakeneko65.kicad_sch]
2023-03-24 Update PCB file to KiCad 7.0
    [rp2040-bakeneko65.kicad_pcb]
2023-03-24 some complete mess with the reset button idk
    [rp2040-bakeneko65.kicad_pcb]
2023-04-01 replacing MCU, some col traces
    [SwitchMatrix.kicad_sch, rp2040-bakeneko65.kicad_pcb]
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2023-04-02 actually place encoder correctly
    [SwitchMatrix.kicad_sch, rp2040-bakeneko65.kicad_pcb, rp2040-bakeneko65.kicad_sch]
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2023-04-04 A couple decoupling caps
    [rp2040-bakeneko65.kicad_pcb]
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2023-04-07 get started on flash
    [rp2040-bakeneko65.kicad_pcb]
2023-04-07 flash, redo ESD, some other stuff
    [rp2040-bakeneko65.kicad_pcb, rp2040-bakeneko65.kicad_sch]
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2023-04-07 add caps lock LED (also route SRV05 properly)
    [rp2040-bakeneko65.kicad_pcb]
2023-04-07 LED + decoupling caps + a lot of stuff
    [rp2040-bakeneko65.kicad_pcb, rp2040-bakeneko65.kicad_sch]
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2023-04-08 (poorly) route debug header
    [rp2040-bakeneko65.kicad_pcb]
2023-04-08 incomplete attempt at routing power
    [rp2040-bakeneko65.kicad_pcb]
2023-04-08 some more power progress
    [rp2040-bakeneko65.kicad_pcb]
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2023-04-08 col routing sucked too much
    [rp2040-bakeneko65.kicad_pcb]
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2023-04-09 Revert "more col routing"
    This reverts commit cb50b5119402ddcb1d4d4028dc95a6a712835f21.
    [rp2040-bakeneko65.kicad_pcb, rp2040-bakeneko65.kicad_sch]
2023-04-09 MCU reposition + a couple cols
    [rp2040-bakeneko65.kicad_pcb, rp2040-bakeneko65.kicad_sch]
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2023-04-09 row routing (not into MCU)
    [rp2040-bakeneko65.kicad_sch]
2023-04-09 really ugly MCU row routing
    [rp2040-bakeneko65.kicad_pcb]
2023-04-09 oops, forgot some stuff
    [rp2040-bakeneko65.kicad_pcb]
2023-04-09 one more diode connection
    [rp2040-bakeneko65.kicad_pcb]
2023-04-09 oops, have to connect col0 as well
    [rp2040-bakeneko65.kicad_pcb, rp2040-bakeneko65.kicad_sch]
2023-04-09 wire knob to MCU in schematic (+ a GND via)
    [rp2040-bakeneko65.kicad_pcb, rp2040-bakeneko65.kicad_sch]
2023-04-15 add initial plate file
    [plate.dxf]
2023-04-15 dot some ground vias around
    [rp2040-bakeneko65.kicad_pcb]
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2023-04-15 screw the knob (+ a couple minor changes)
    [SwitchMatrix.kicad_sch, rp2040-bakeneko65.kicad_pcb, rp2040-bakeneko65.kicad_sch]
2023-04-16 JLC tools + C9 needed a bigger footprint
    [rp2040-bakeneko65.kicad_sch]
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2023-04-19 swap to PCM footprints
    [SwitchMatrix.kicad_sch, rp2040-bakeneko65.kicad_pcb, rp2040-bakeneko65.kicad_sch]
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2023-04-19 failed attempt at making a plate with kicad
    [SwitchMatrix.kicad_sch, rp2040-bakeneko65-B_Cu.dxf, rp2040-bakeneko65-Edge_Cuts.dxf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]
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2023-04-23 just a bit of bottom row to go
    [rp2040-bakeneko65.kicad_pcb]
2023-04-28 plate maybe finalised
    I just copy pasted the outline from the bakeneko65 plate lmao
    [keebio-plate-maybe-final.dxf, keebio-plate.FCStd]
2023-05-02 text + routing some traces away from holes
    [rp2040-bakeneko65.kicad_pcb]
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2023-05-02 misc improvements + new gerbers
    debug text, no connection flags on unused GPIOs, etc
    [BOM-rp2040-bakeneko65.csv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]
2023-05-06 swap out terminating resistors for 0603
    [rp2040-bakeneko65.kicad_pcb, rp2040-bakeneko65.kicad_sch]
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2023-05-12 fix via clearance issues
    [rp2040-bakeneko65.kicad_pcb]
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2023-05-15 moved COL traces around a bit
    also fixed C6 text positioning
    [rp2040-bakeneko65.kicad_pcb]
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2023-05-18 fix crystal routing, sprinkle stitching vias around, etc
    also move some traces around
    [rp2040-bakeneko65.kicad_pcb]
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2023-05-19 swap fuse to 1206 (again)
    accidentally mistook a ferrite bead for a fuse when I changed the fuse footprint to 0805, back to 1206 we go
    [BOM-rp2040-bakeneko65.csv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]
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2023-05-21 adding info to title block
    plus plate file rename
    [SwitchMatrix.kicad_sch, rp2040-bakeneko65.kicad_pcb, rp2040-bakeneko65.kicad_sch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]
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2023-06-22 quite a few changes
    fix switch routing, update footprints, couple other minor tweaks
    [rp2040-bakeneko65.kicad_pcb]
2023-06-22 fix capacitor alignment
    [rp2040-bakeneko65.kicad_pcb]
2023-06-23 hopefully final production files
    and a "fixed" plate (turns out the plate didn't need fixing)
    [keebio-plate-fixed.FCStd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]
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2023-06-25 even newer production files because I'm paranoid
    also the ones I ordered my proto with
    [rp2040-bakeneko65-B_Cu.gbr, rp2040-bakeneko65-B_Mask.gbr, rp2040-bakeneko65-B_Paste.gbr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]
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2023-08-13 add PCB image to readme
    also add a not working firmware script KLE
    [rp2040-bakeneko65.kicad_pcb]
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

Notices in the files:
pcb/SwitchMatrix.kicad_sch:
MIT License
